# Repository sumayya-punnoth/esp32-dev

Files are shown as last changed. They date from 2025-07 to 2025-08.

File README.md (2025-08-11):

# ESP32 Dev Kit

This is a custom PCB of the ESP32 development board designed in KiCad using the official Espressif documentation as reference.

3D model of the PCB

## Viewing the project
1. Clone the repository:
```bash
git clone https://github.com/sumayya-punnoth/esp32-dev
```
2. Open `esp32_dev.kicad_pro` to view the schematic and PCB layout.

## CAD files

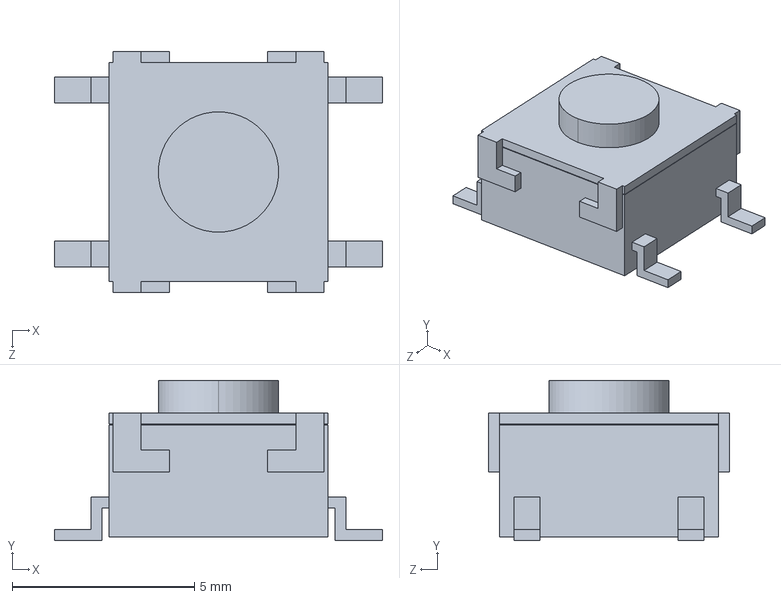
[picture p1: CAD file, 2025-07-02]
B3S-1000/B3S-1000.step
9.00 x 4.40 x 6.60 mm

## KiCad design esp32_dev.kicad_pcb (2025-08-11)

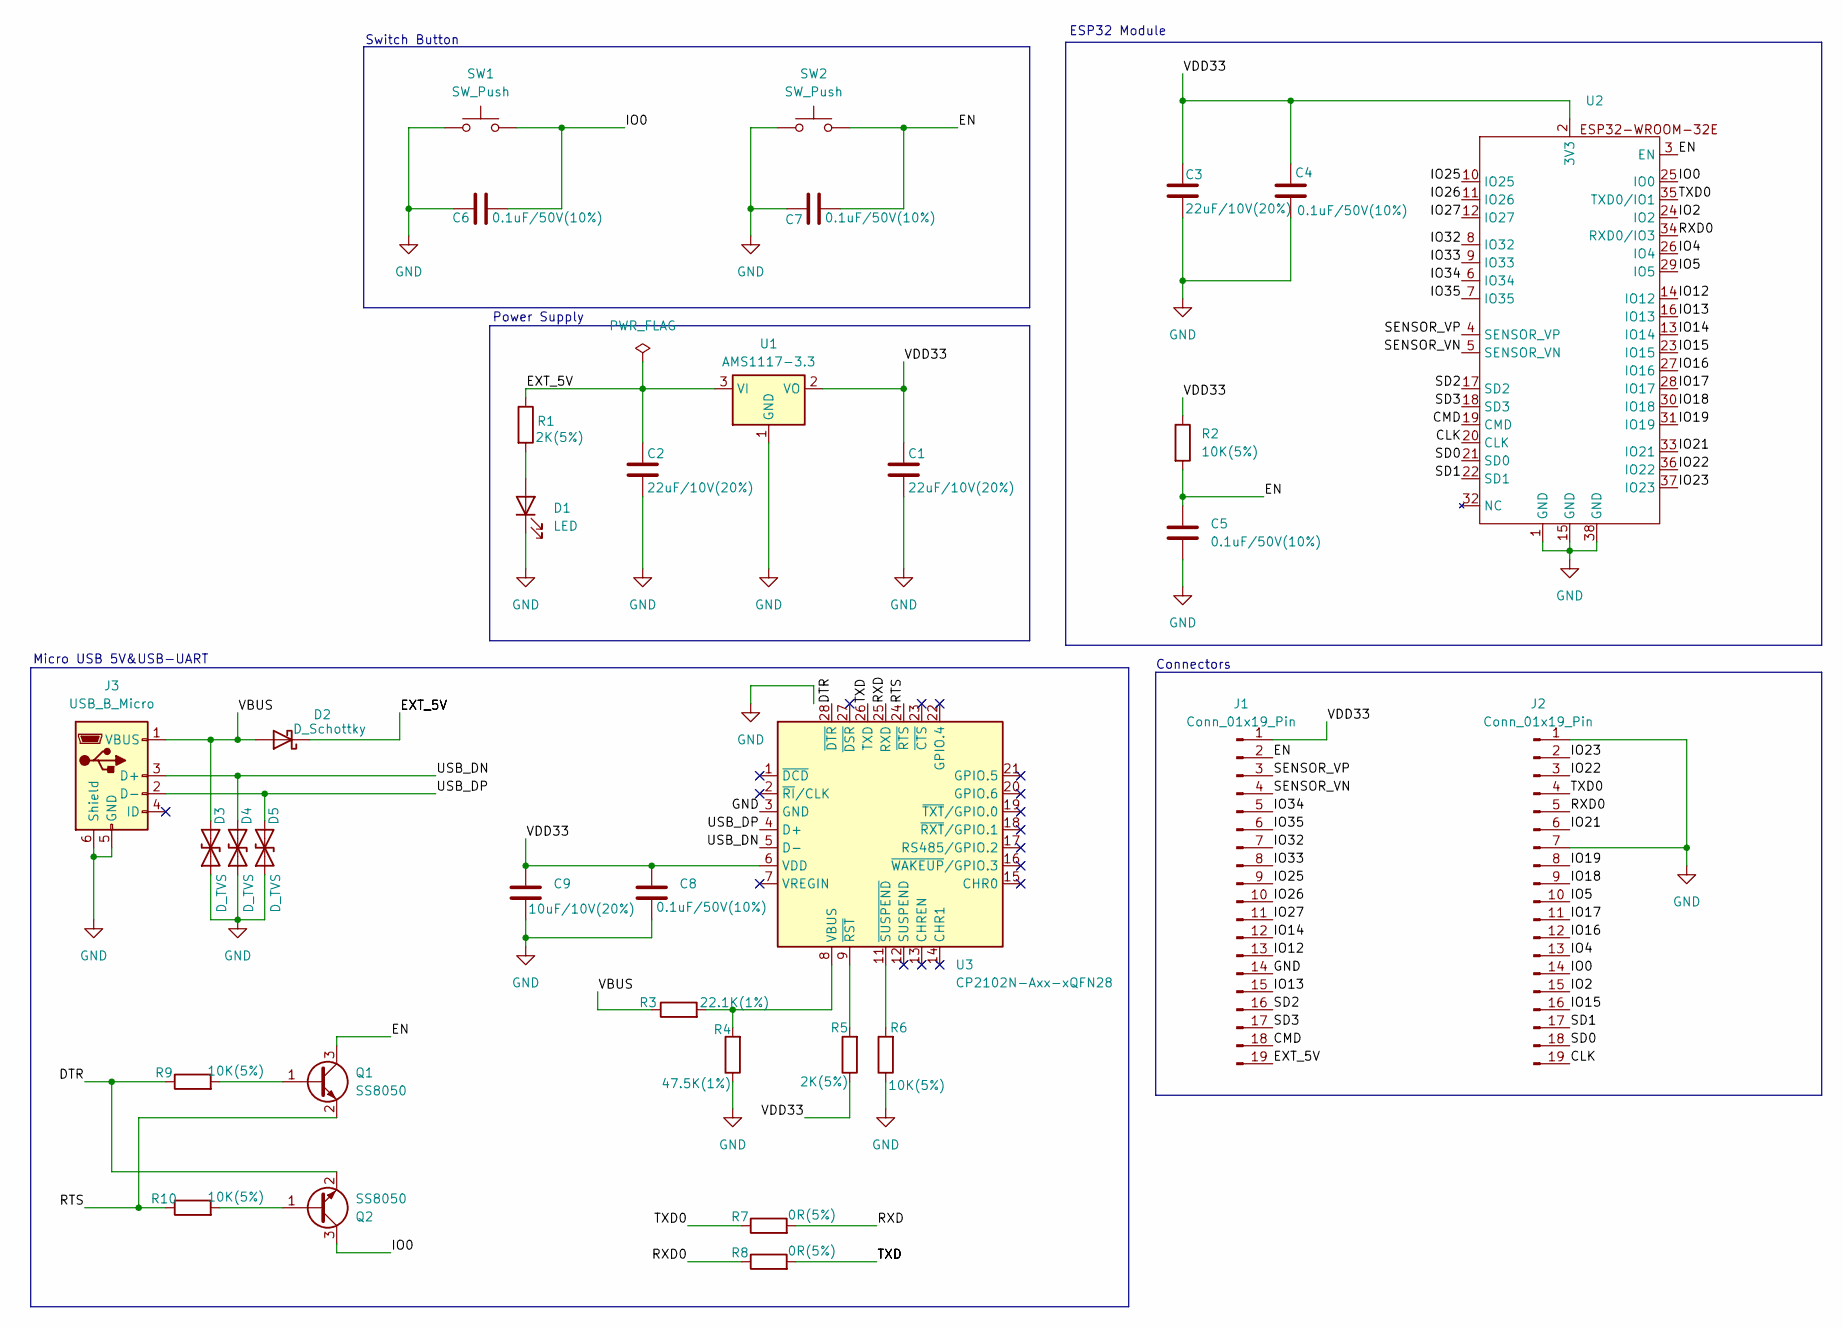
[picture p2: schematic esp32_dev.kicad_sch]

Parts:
C1, C2, C3: 22uF/10V(20%); C_0201_0603Metric
C4, C5, C6, C7, C8: 0.1uF/50V(10%); C_01005_0402Metric
C9: 10uF/10V(20%); C_01005_0402Metric
D1: LED; LED_0603_1608Metric
D2: D_Schottky; D_SOD-323
D3, D4, D5: D_TVS; D_SOD-523
J1, J2: Conn_01x19_Pin; PinHeader_1x19_P2.54mm_Vertical
J3: USB_B_Micro; USB_Micro-AB_Molex_47590-0001
Q1, Q2: SS8050; SOT-23
R1, R5: 2K(5%); R_01005_0402Metric
R2, R6, R9, R10: 10K(5%); R_01005_0402Metric
R3: 22.1K(1%); R_01005_0402Metric
R4: 47.5K(1%); R_01005_0402Metric
R7, R8: 0R(5%); R_01005_0402Metric
SW1, SW2: SW_Push; SW_SPST_B3S-1000
U1: AMS1117-3.3; SOT-223-3_TabPin2
U2: Untitled
U3: CP2102N-Axx-xQFN28; QFN-28-1EP_5x5mm_P0.5mm_EP3.35x3.35mm

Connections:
/CLK: J2.19, U2.20 (CLK)
/CMD: J1.18, U2.19 (CMD)
/DTR: Q2.2 (E), R9.1, U3.28 (~DTR)
/EN: C5.1, C7.1, J1.2, Q1.3 (C), R2.2, SW2.2, U2.3 (EN); also elsewhere on the board
/EXT_5V: C2.1, D2.1 (K), J1.19, R1.1, U1.3 (VI)
/IO0: C6.1, J2.14, Q2.3 (C), SW1.2, U2.25 (IO0); also elsewhere on the board
/IO2: J2.15, U2.24 (IO2)
/IO4: J2.13, U2.26 (IO4)
/IO5: J2.10, U2.29 (IO5)
/IO12: J1.13, U2.14 (IO12)
/IO13: J1.15, U2.16 (IO13)
/IO14: J1.12, U2.13 (IO14)
/IO15: J2.16, U2.23 (IO15)
/IO16: J2.12, U2.27 (IO16)
/IO17: J2.11, U2.28 (IO17)
/IO18: J2.9, U2.30 (IO18)
/IO19: J2.8, U2.31 (IO19)
/IO21: J2.6, U2.33 (IO21)
/IO22: J2.3, U2.36 (IO22)
/IO23: J2.2, U2.37 (IO23)
/IO25: J1.9, U2.10 (IO25)
/IO26: J1.10, U2.11 (IO26)
/IO27: J1.11, U2.12 (IO27)
/IO32: J1.7, U2.8 (IO32)
/IO33: J1.8, U2.9 (IO33)
/IO34: J1.5, U2.6 (IO34)
/IO35: J1.6, U2.7 (IO35)
/RTS: Q1.2 (E), R10.1, U3.24 (~RTS)
/RXD: R7.2, U3.25 (RXD)
/RXD0: J2.5, R8.1, U2.34 (RXD0/IO3)
/SD0: J2.18, U2.21 (SD0)
/SD1: J2.17, U2.22 (SD1)
/SD2: J1.16, U2.17 (SD2)
/SD3: J1.17, U2.18 (SD3)
/SENSOR_VN: J1.4, U2.5 (SENSOR_VN)
/SENSOR_VP: J1.3, U2.4 (SENSOR_VP)
/TXD: R8.2, U3.26 (TXD)
/TXD0: J2.4, R7.1, U2.35 (TXD0/IO1)
/USB_DN: D4.2 (A2), J3.3 (D+), U3.5 (D-)
/USB_DP: D5.2 (A2), J3.2 (D-), U3.4 (D+)
/VBUS: D2.2 (A), D3.2 (A2), J3.1 (VBUS), R3.1
/VDD33: C1.1, C3.1, C4.1, C8.1, C9.1, J1.1, R2.1, R5.1, U1.2 (VO), U2.2 (3V3), U3.6 (VDD)
GND: C1.2, C2.2, C3.2, C4.2, C5.2, C6.2, C7.2, C8.2, C9.2, D1.1 (K), D3.1 (A1), D4.1 (A1), D5.1 (A1), J1.14, J2.1, J2.7, J3.5 (GND), J3.6 (Shield), R4.1, R6.1, SW1.1, SW2.1, U1.1 (GND), U2.1 (GND), U2.15 (GND), U2.38 (GND), U3.3 (GND), U3.29 (GND); also elsewhere on the board
unnamed: D1.2 (A), R1.2
unnamed: Q1.1 (B), R9.2
unnamed: Q2.1 (B), R10.2
unnamed: R3.2, R4.2, U3.8 (VBUS)
unnamed: R5.2, U3.9 (~RST)
unnamed: R6.2, U3.11 (~SUSPEND)

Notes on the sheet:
Switch Button
Connectors
Power Supply
ESP32 Module
Micro USB 5V&USB-UART

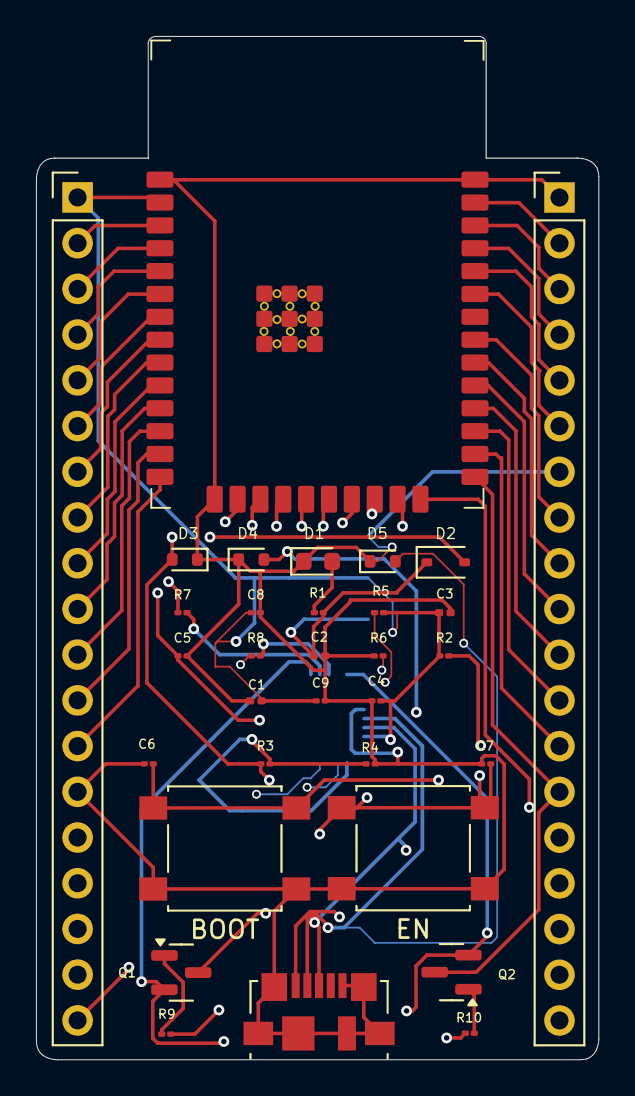
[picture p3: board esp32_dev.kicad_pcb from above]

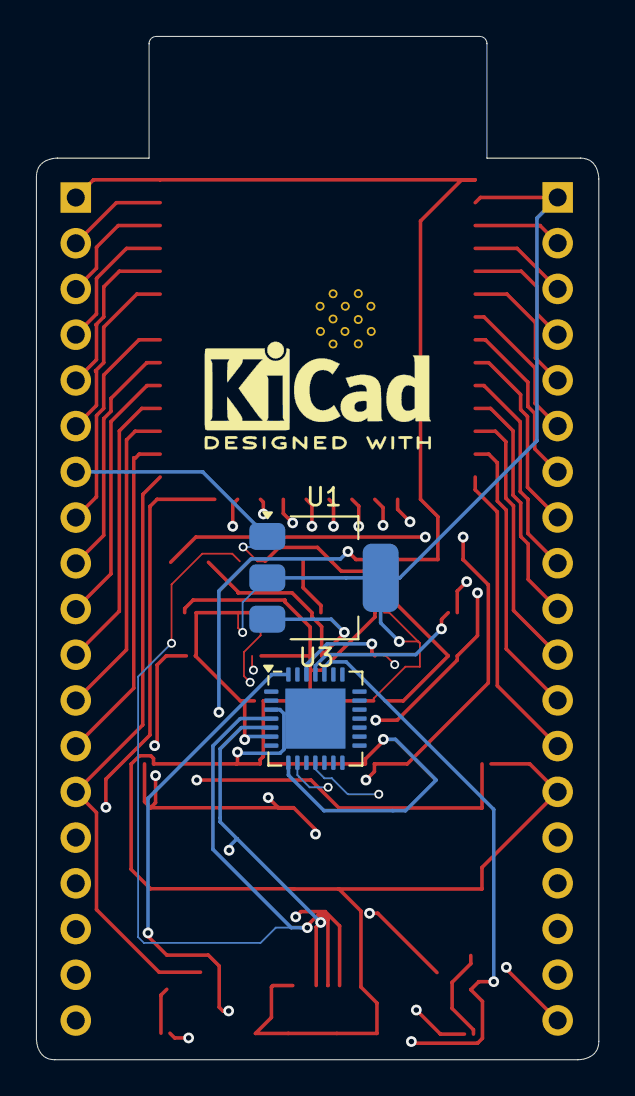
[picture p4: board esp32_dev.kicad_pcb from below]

Board: 4 copper layers, 31.2 x 56.8 mm, 34 parts (2 on the bottom side), 49 nets.

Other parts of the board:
BOOT: SW_Push; SW_SPST_B3S-1000
EN: SW_Push; SW_SPST_B3S-1000

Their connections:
/EN: EN.2; also elsewhere on the board
/IO0: BOOT.2; also elsewhere on the board
GND: BOOT.1, EN.1; also elsewhere on the board
